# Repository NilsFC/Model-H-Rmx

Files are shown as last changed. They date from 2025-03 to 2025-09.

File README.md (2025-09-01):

# **Model H Remix 2.0**

## Replacement Model M controller board

Project wiki: https://github.com/NilsFC/Model-H-Rmx/wiki

## **What's new in 2.0?**

-The "Notch": increased compatibility with all Model M cases;<br>
-The "Experimental Area": on-board support to Solenoid;<br>
-The "Testpoints": all testpoint grouped together with Solenoid and one extra I/O available to users;<br>

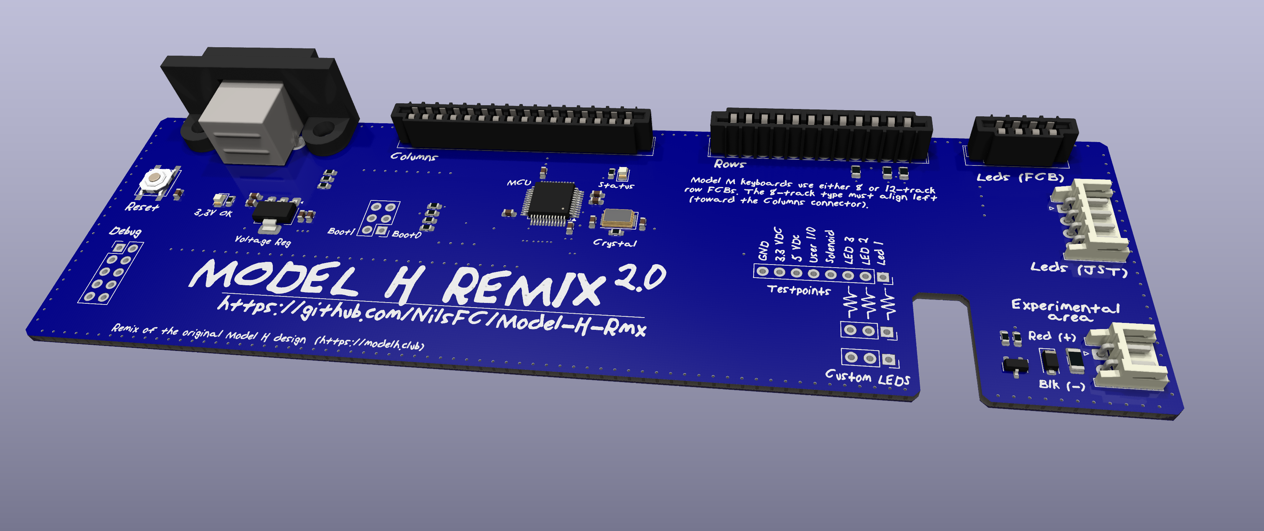
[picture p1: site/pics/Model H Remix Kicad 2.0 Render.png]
Model H Remix Kicad Render


## **Description**

This board is a direct replacement controller for the classic IBM Model M keyboards.<br>
Old mechanical keyboards are making a comeback among enthusiasts and programmers and gaining value.<br>
Unfortunately, modern computers no longer have DIN or PS2 ports, so there’s no simple way to connect a 40-year-old hardware to a brand-new laptop.<br>
By replacing the legacy electronics inside the keyboard, it’s possible to revive a “piece of history” and even add modern functions like USB connectivity and remappable characters. The original PCB can be preserved to revert the keyboard to its original state.<br>

The "Model H Remix" is designed to fit and work with standard 101/102/85/86 keys keyboards.<br>

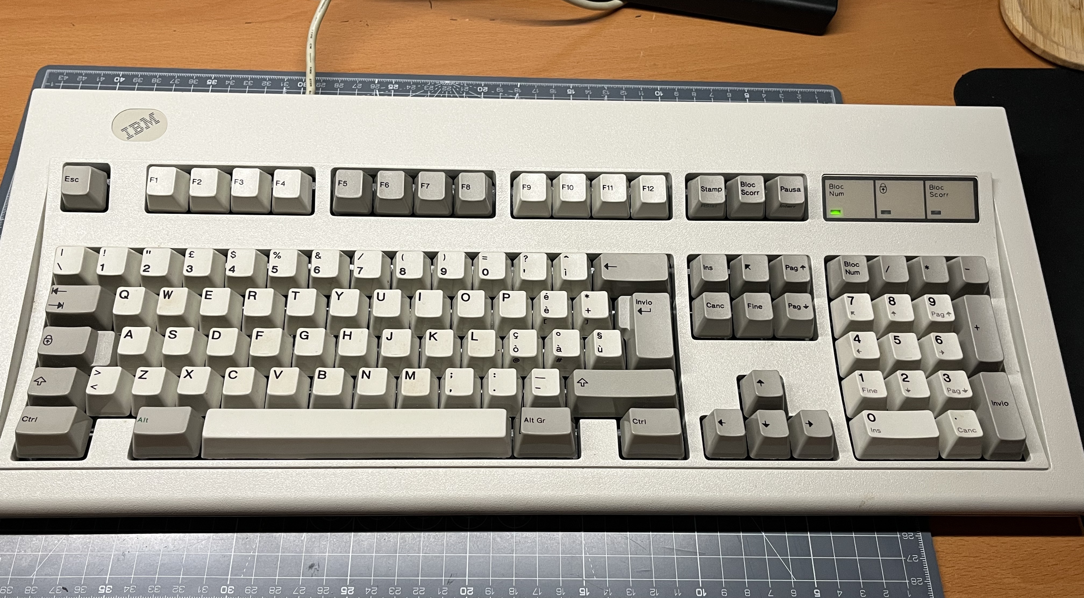
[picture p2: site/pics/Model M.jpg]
Model M


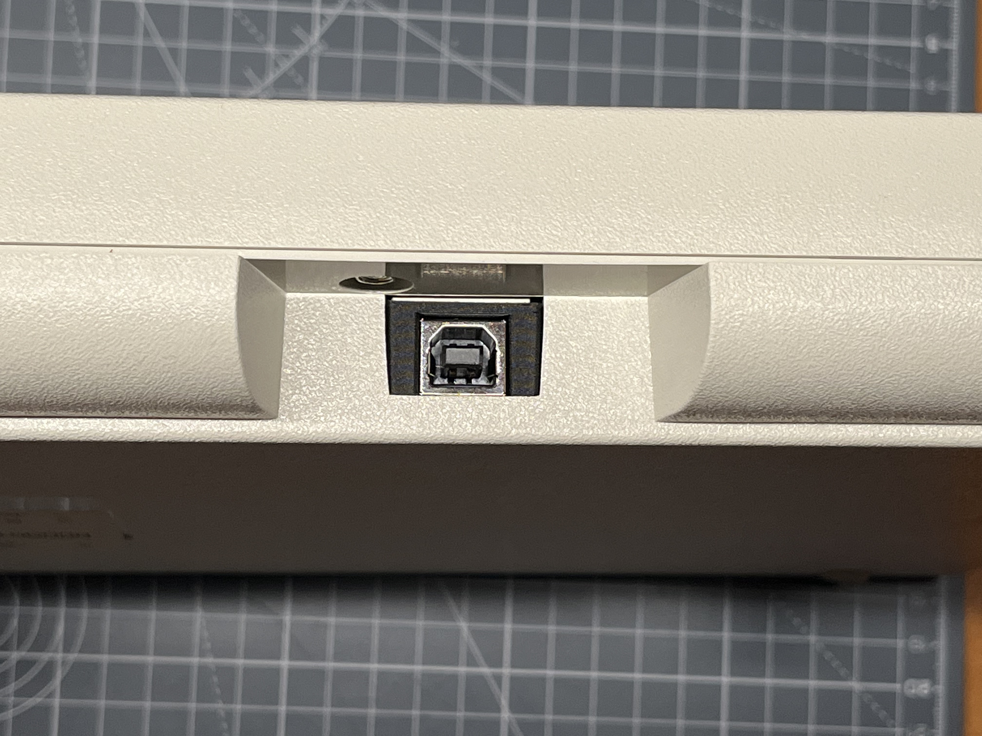
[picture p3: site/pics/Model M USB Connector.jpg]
Model M USB Connector


## **Credits**

This version is just a rework of the original design from **John Hawthorn**. <br>
Check out the fantastic work of this guy to whom I am very grateful. Thanks to his Open Source project I really learned a lot. [Model H Project](https://modelh.club/)
<br>

Gratitude goes also to **Jerome Berclaz** for his update work on the Model H software in QMK and QMK-Vial firmware. https://github.com/jberclaz/modelh

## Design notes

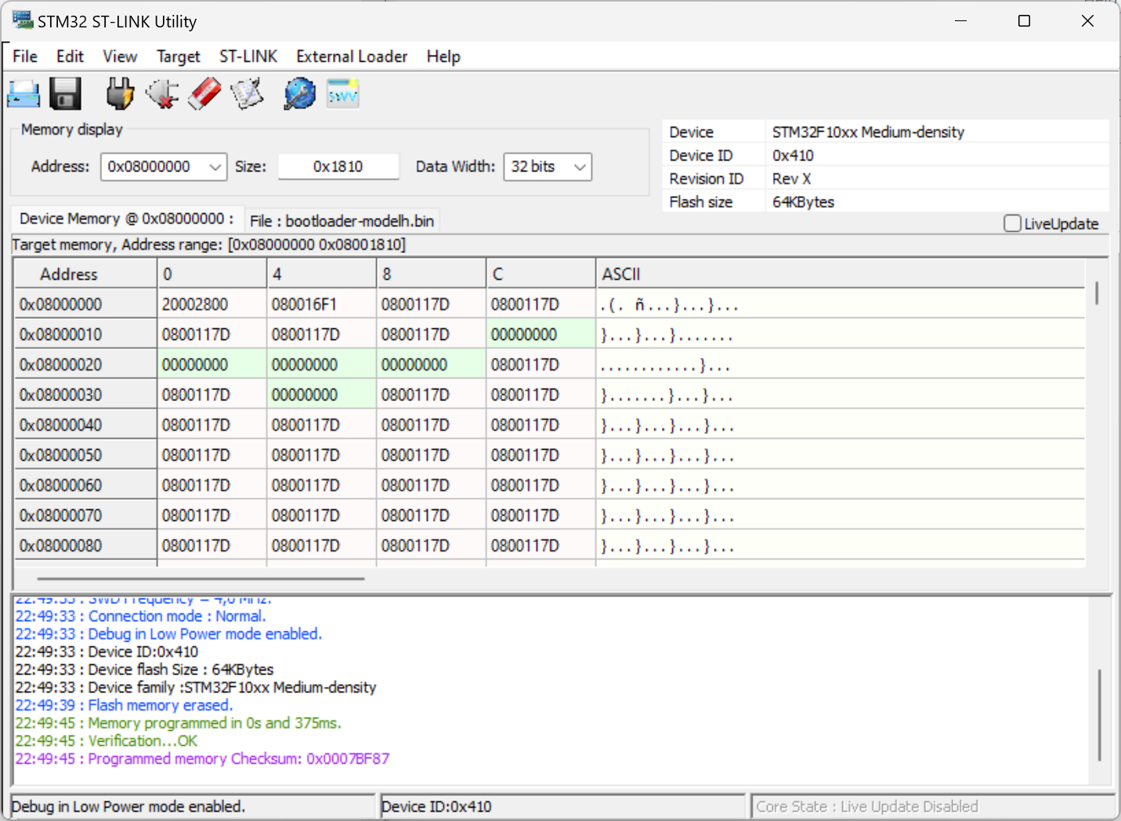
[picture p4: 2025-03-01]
site/pics/STM32-STLink.png

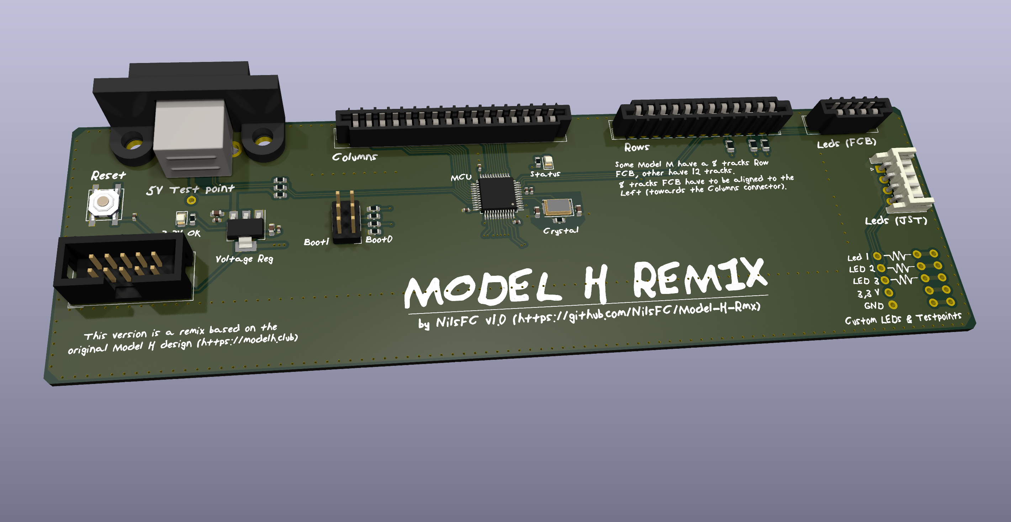
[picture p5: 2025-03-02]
site/pics/Model H Remix Kicad Render.png

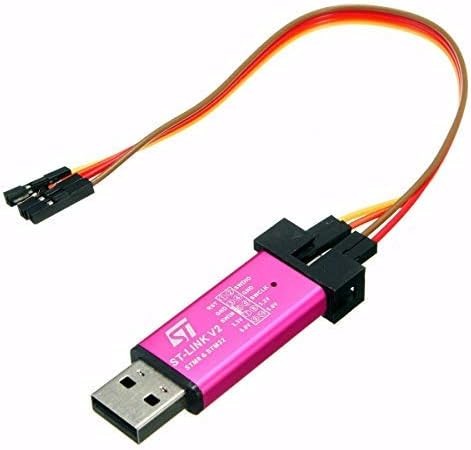
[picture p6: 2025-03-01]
site/pics/ST Link v2.jpg

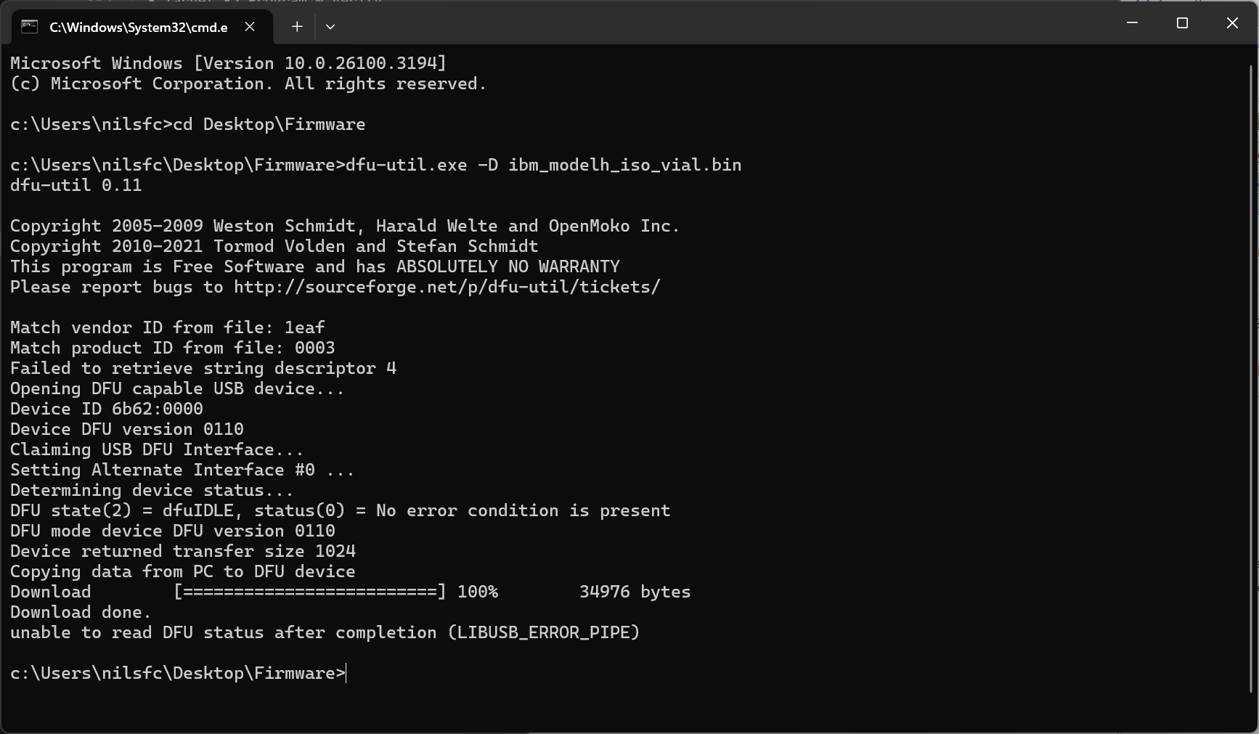
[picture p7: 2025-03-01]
site/pics/dfu-util command prompt screenshot.png

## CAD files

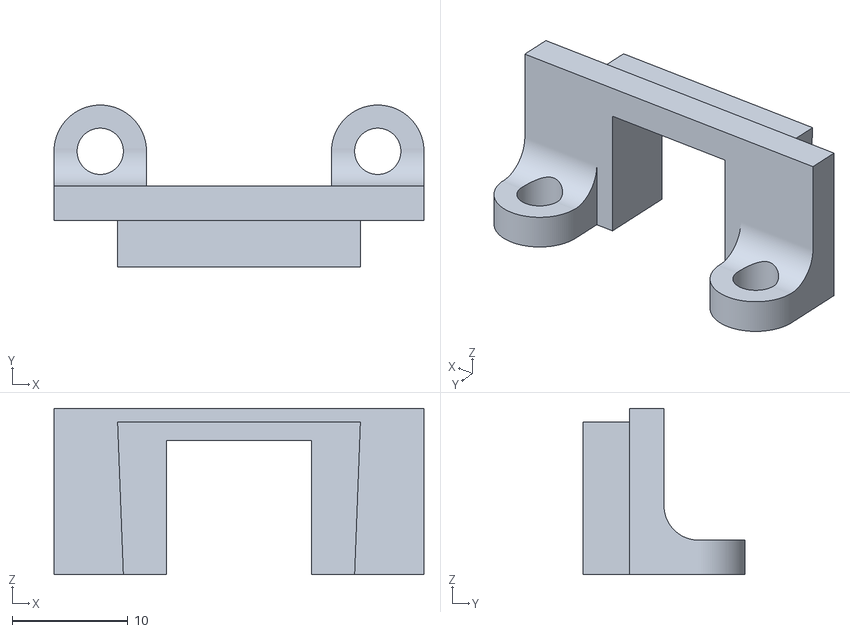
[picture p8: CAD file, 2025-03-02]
Mechanical/shim.stl
32.0 x 14.0 x 14.4

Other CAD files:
Mechanical/shim.scad

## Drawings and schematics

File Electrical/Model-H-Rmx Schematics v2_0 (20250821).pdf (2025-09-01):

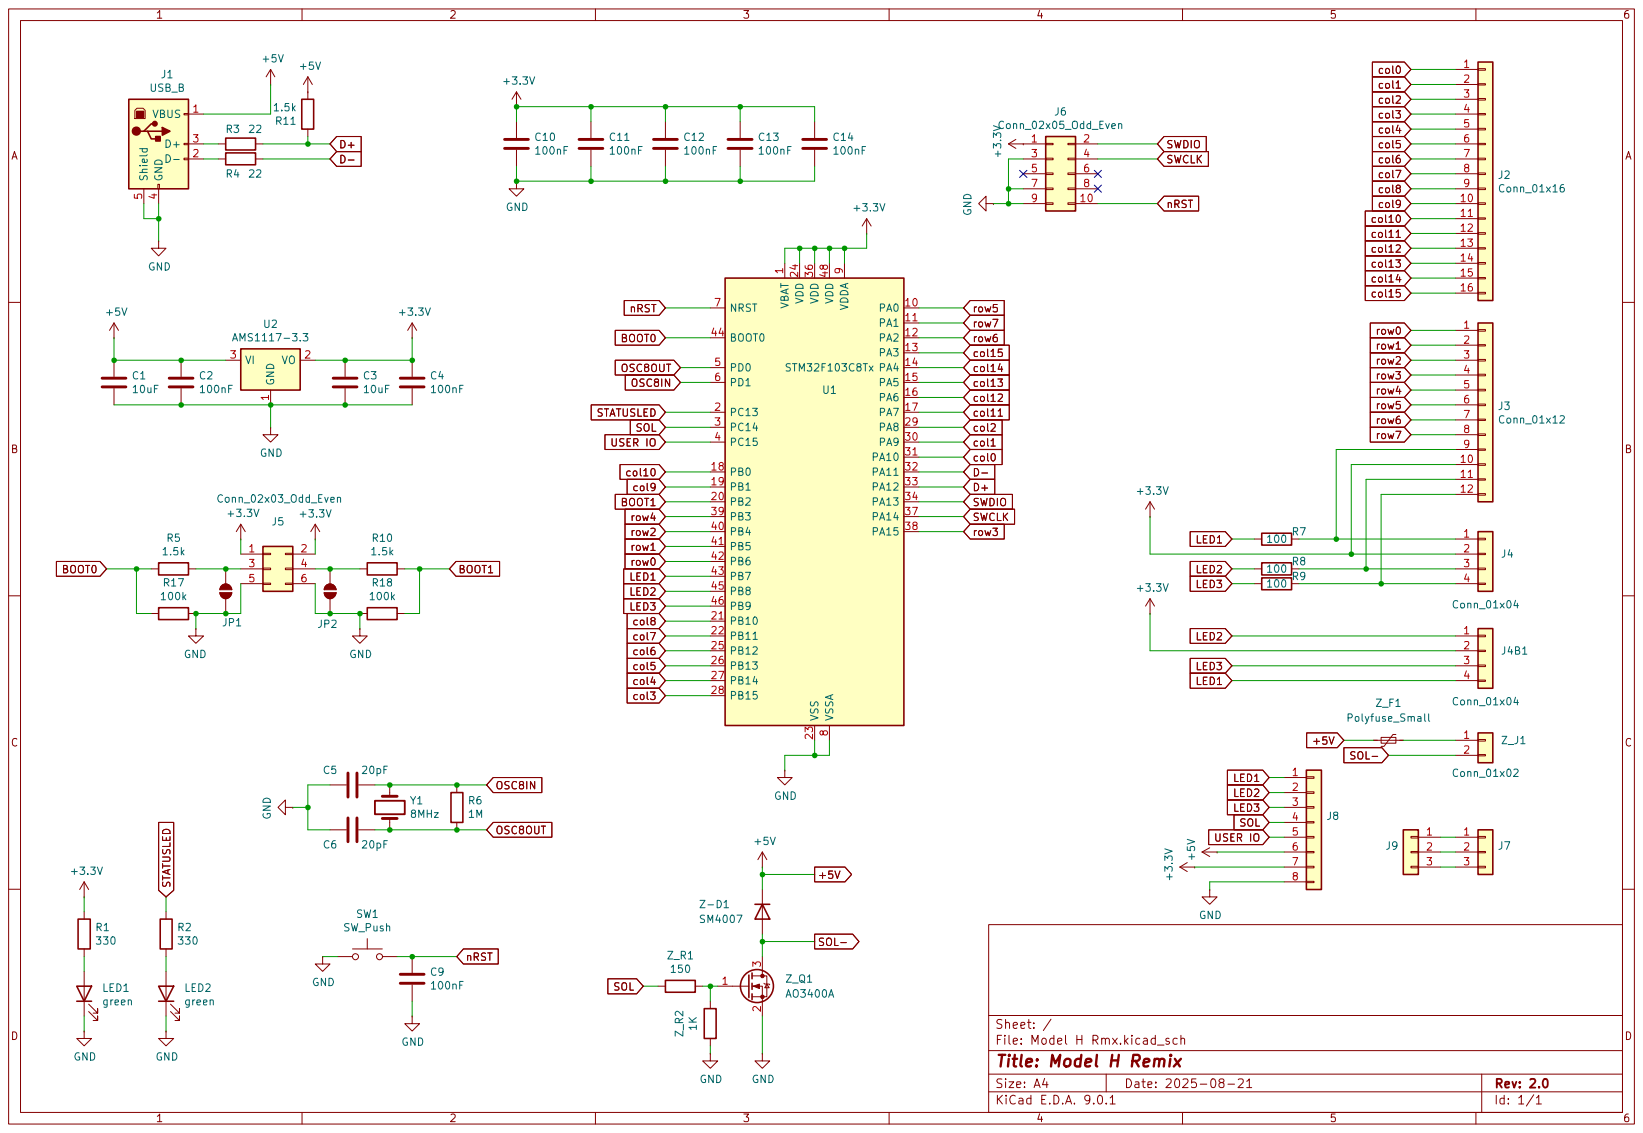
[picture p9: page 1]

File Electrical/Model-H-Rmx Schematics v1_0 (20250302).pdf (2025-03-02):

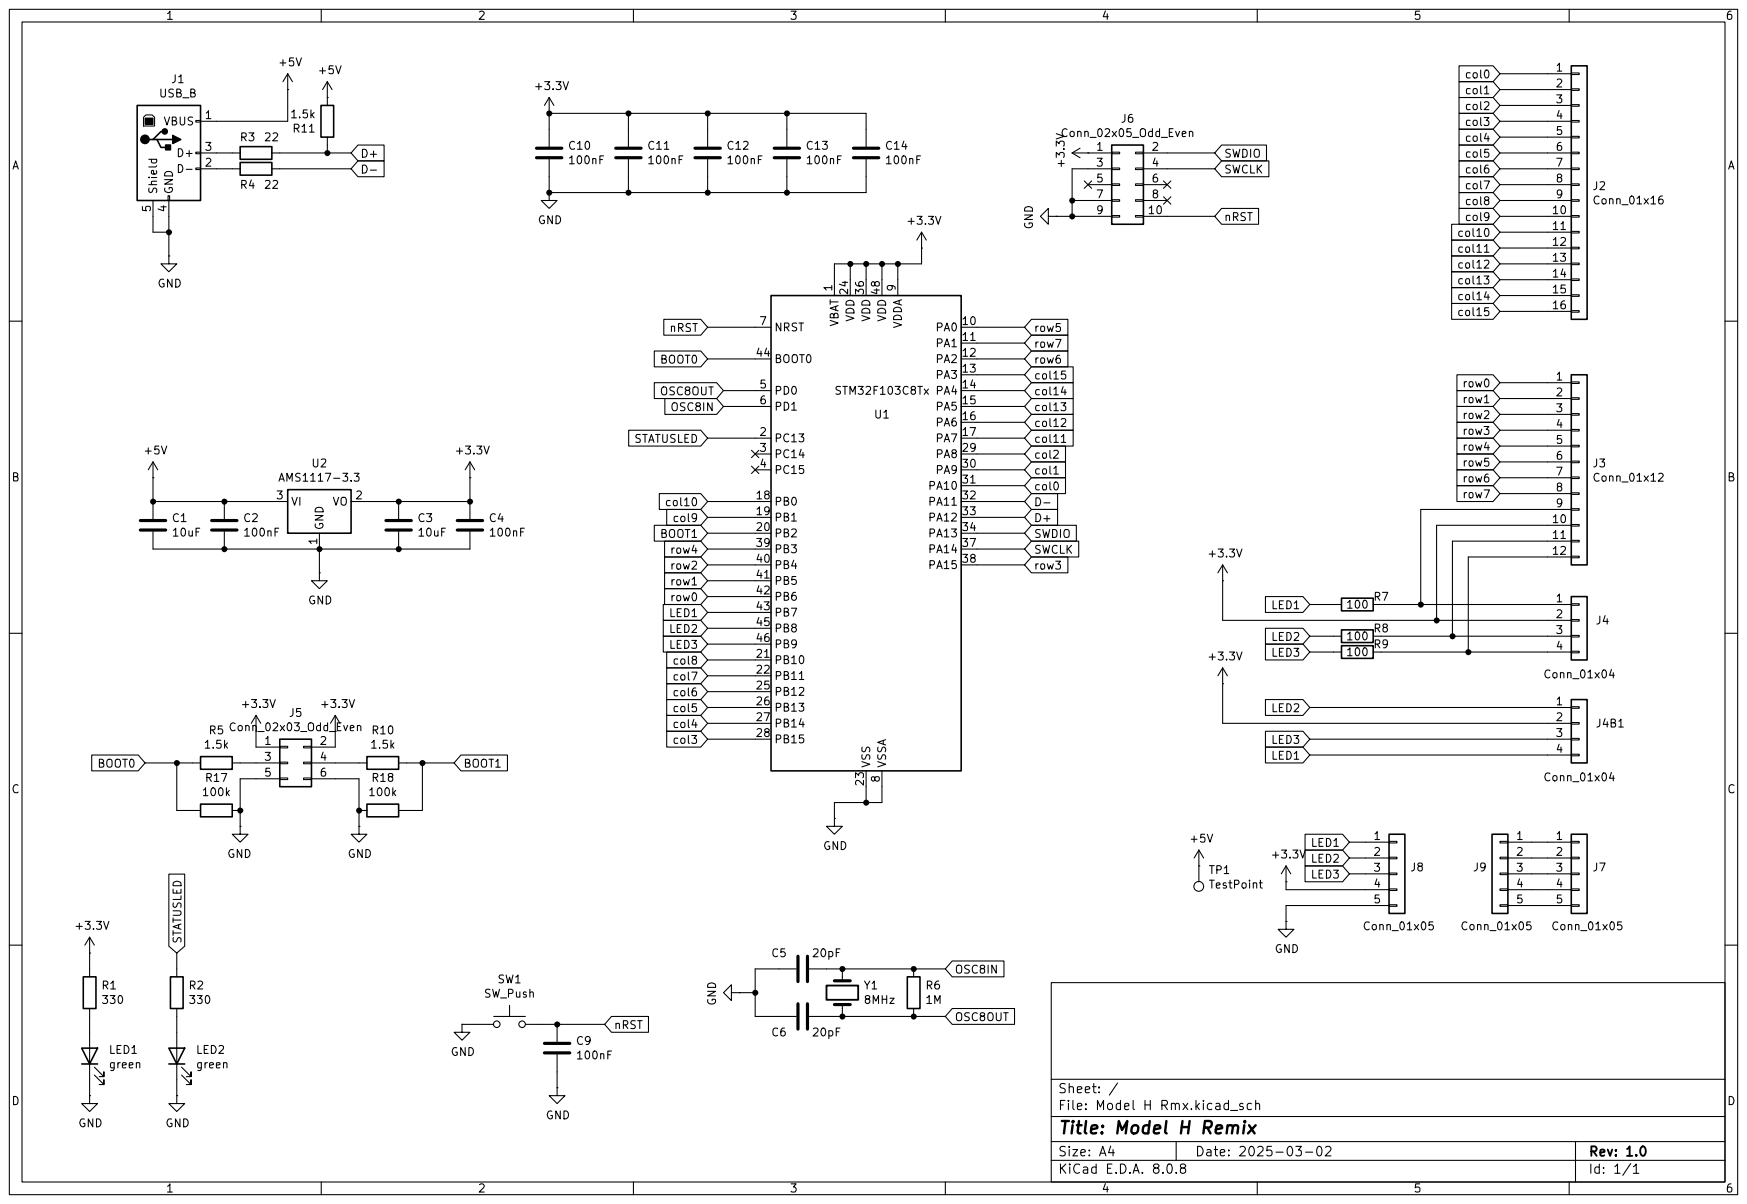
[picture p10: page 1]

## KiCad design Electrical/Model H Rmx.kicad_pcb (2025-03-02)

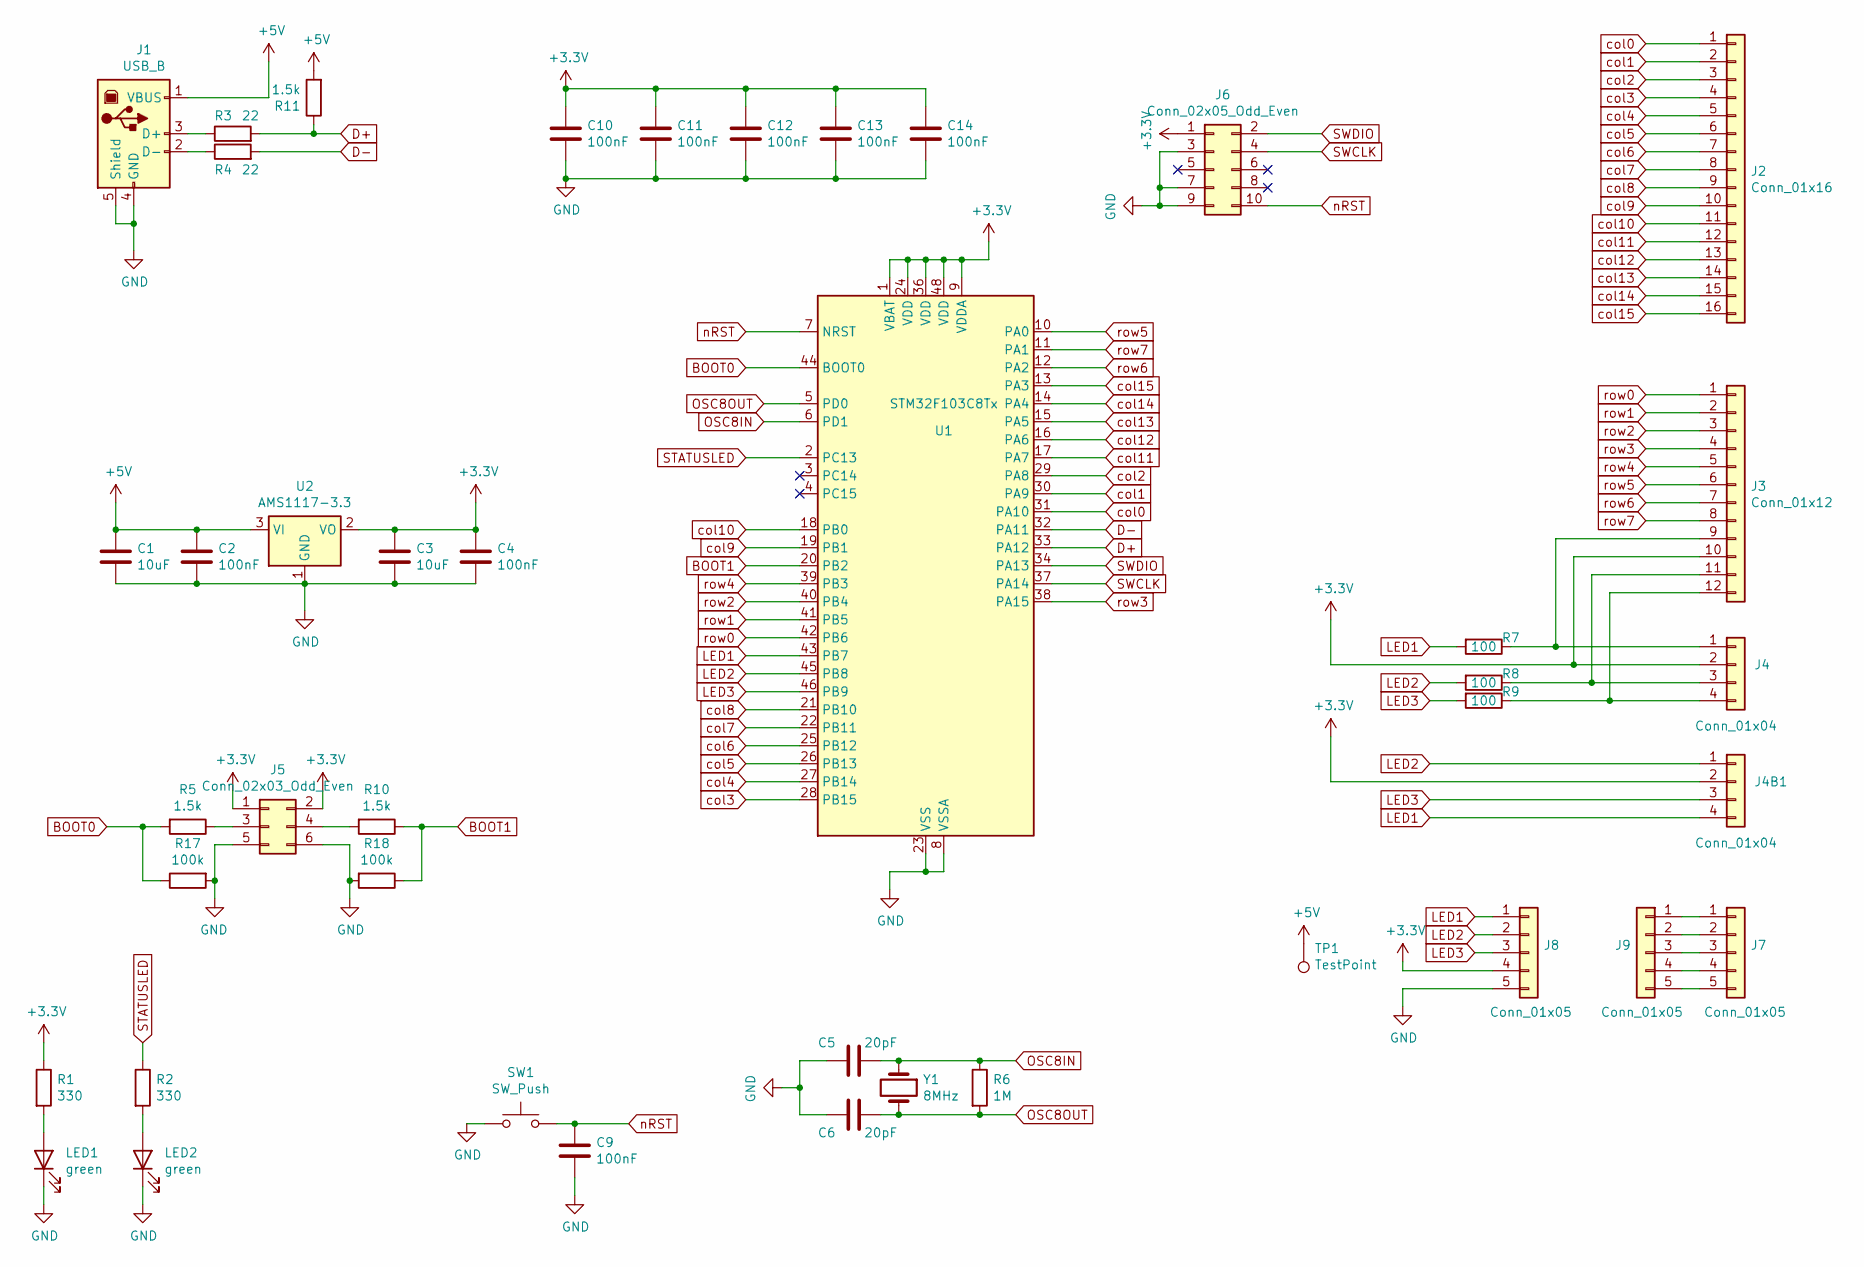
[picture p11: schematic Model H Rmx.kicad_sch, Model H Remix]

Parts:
C1, C3: 10uF; C_0603_1608Metric; LCSC C19702
C2, C4, C9, C10, C11, C12, C13, C14: 100nF; C_0603_1608Metric; LCSC C1525
C5, C6: 20pF; C_0603_1608Metric; LCSC C1653
J1: USB_B; USB_B_OST_USB-B1HSxx_Horizontal
J2: Conn_01x16; Model1-triomate-cols16
J3: Conn_01x12; Model1-triomate-rows12
J4: Conn_01x04; Model1-triomate-leds4
J4B1: Conn_01x04; JST_EH_S4B-EH_1x04_P2.50mm_Horizontal
J5: Conn_02x03_Odd_Even; PinHeader_2x03_P2.54mm_Vertical
J6: Conn_02x05_Odd_Even; IDC-Header_2x05_P2.54mm_Vertical
J7, J8, J9: Conn_01x05; PinSocket_1x05_P2.54mm_Vertical
LED1, LED2: green; LED_0805_2012Metric; LCSC C2297
R1, R2: 330; R_0603_1608Metric; LCSC C23138
R3, R4: 22; R_0603_1608Metric; LCSC C23345
R5, R10, R11: 1.5k; R_0603_1608Metric; LCSC C22843
R6: 1M; R_0603_1608Metric; LCSC C22935
R7, R8, R9: 100; R_0805_2012Metric; LCSC C17408
R17, R18: 100k; R_0603_1608Metric; LCSC C25803
SW1: SW_Push; SW_SPST_EVPBF; LCSC C318888
TP1: TestPoint; TestPoint_THTPad_D1.5mm_Drill0.7mm
U1: STM32F103C8Tx; LQFP-48_7x7mm_P0.5mm; LCSC C8734
U2: AMS1117-3.3; SOT-223-3_TabPin2; LCSC C6186
Y1: 8MHz; Crystal_SMD_5032-2Pin_5.0x3.2mm; LCSC C115962

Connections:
+3.3V: C3.1, C4.1, C10.1, C11.1, C12.1, C13.1, C14.1, J3.10, J4.2, J4B1.2, J5.1, J5.2, J6.1, J8.4, R1.1, U1.1 (VBAT), U1.9 (VDDA), U1.24 (VDD), U1.36 (VDD), U1.48 (VDD), U2.2 (VO)
+5V: C1.1, C2.1, J1.1 (VBUS), R11.2, TP1.1, U2.3 (VI)
BOOT0: R5.2, R17.1, U1.44 (BOOT0)
BOOT1: R10.1, R18.1, U1.20 (PB2)
D+: R3.2, R11.1, U1.33 (PA12)
D-: R4.2, U1.32 (PA11)
GND: C1.2, C2.2, C3.2, C4.2, C5.2, C6.2, C9.2, C10.2, C11.2, C12.2, C13.2, C14.2, J1.4 (GND), J1.5 (Shield), J5.5, J5.6, J6.3, J6.7, J6.9, J8.5, LED1.1 (K), LED2.1 (K), R17.2, R18.2, SW1.1, U1.8 (VSSA), U1.23 (VSS), U1.35 (VSS), U1.47 (VSS), U2.1 (GND)
LED1: J4B1.4, J8.1, R7.2, U1.43 (PB7)
LED2: J4B1.1, J8.2, R8.2, U1.45 (PB8)
LED3: J4B1.3, J8.3, R9.2, U1.46 (PB9)
unnamed: J1.3 (D+), R3.1
unnamed: J1.2 (D-), R4.1
unnamed: J3.9, J4.1, R7.1
unnamed: J3.11, J4.3, R8.1
unnamed: J3.12, J4.4, R9.1
unnamed: J5.3, R5.1
unnamed: J5.4, R10.2
unnamed: J7.1, J9.1
unnamed: J7.2, J9.2
unnamed: J7.3, J9.3
unnamed: J7.4, J9.4
unnamed: J7.5, J9.5
unnamed: LED1.2 (A), R1.2
unnamed: LED2.2 (A), R2.2
OSC8IN: C5.1, R6.1, U1.6 (PD1), Y1.1
OSC8OUT: C6.1, R6.2, U1.5 (PD0), Y1.2
STATUSLED: R2.1, U1.2 (PC13)
SWCLK: J6.4, U1.37 (PA14)
SWDIO: J6.2, U1.34 (PA13)
col0: J2.1, U1.31 (PA10)
col1: J2.2, U1.30 (PA9)
col2: J2.3, U1.29 (PA8)
col3: J2.4, U1.28 (PB15)
col4: J2.5, U1.27 (PB14)
col5: J2.6, U1.26 (PB13)
col6: J2.7, U1.25 (PB12)
col7: J2.8, U1.22 (PB11)
col8: J2.9, U1.21 (PB10)
col9: J2.10, U1.19 (PB1)
col10: J2.11, U1.18 (PB0)
col11: J2.12, U1.17 (PA7)
col12: J2.13, U1.16 (PA6)
col13: J2.14, U1.15 (PA5)
col14: J2.15, U1.14 (PA4)
col15: J2.16, U1.13 (PA3)
nRST: C9.1, J6.10, SW1.2, U1.7 (NRST)
row0: J3.1, U1.42 (PB6)
row1: J3.2, U1.41 (PB5)
row2: J3.3, U1.40 (PB4)
row3: J3.4, U1.38 (PA15)
row4: J3.5, U1.39 (PB3)
row5: J3.6, U1.10 (PA0)
row6: J3.7, U1.12 (PA2)
row7: J3.8, U1.11 (PA1)

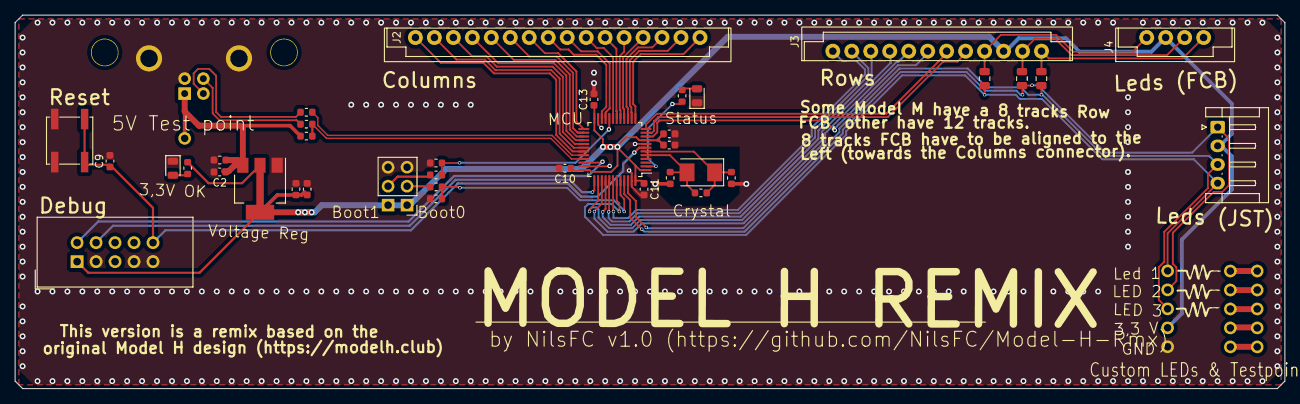
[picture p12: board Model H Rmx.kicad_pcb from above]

Board: 2 copper layers, 170.0 x 50.0 mm, 42 parts (0 on the bottom side), 54 nets.

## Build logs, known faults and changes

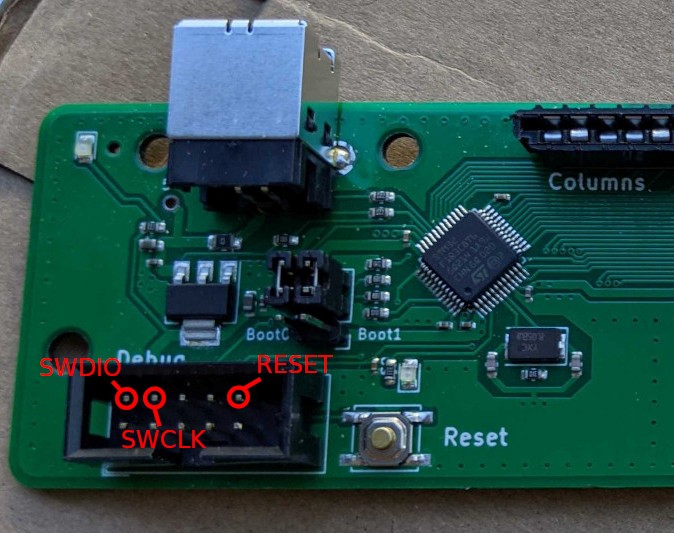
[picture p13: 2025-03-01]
site/pics/Debug connector pinout.jpg
